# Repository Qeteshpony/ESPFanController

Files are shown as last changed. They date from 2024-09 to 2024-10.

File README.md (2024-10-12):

# ESPFanController



3D Render
3D Render

[Hardware Documentation](https://qeteshpony.github.io/ESPFanController)

Controller for up to three 5V or 12V PWM-Fans with an ESP32 at it's core 

The included yaml file is my config for ESP-Home but of course this can also be programmed in any compatible language you like...

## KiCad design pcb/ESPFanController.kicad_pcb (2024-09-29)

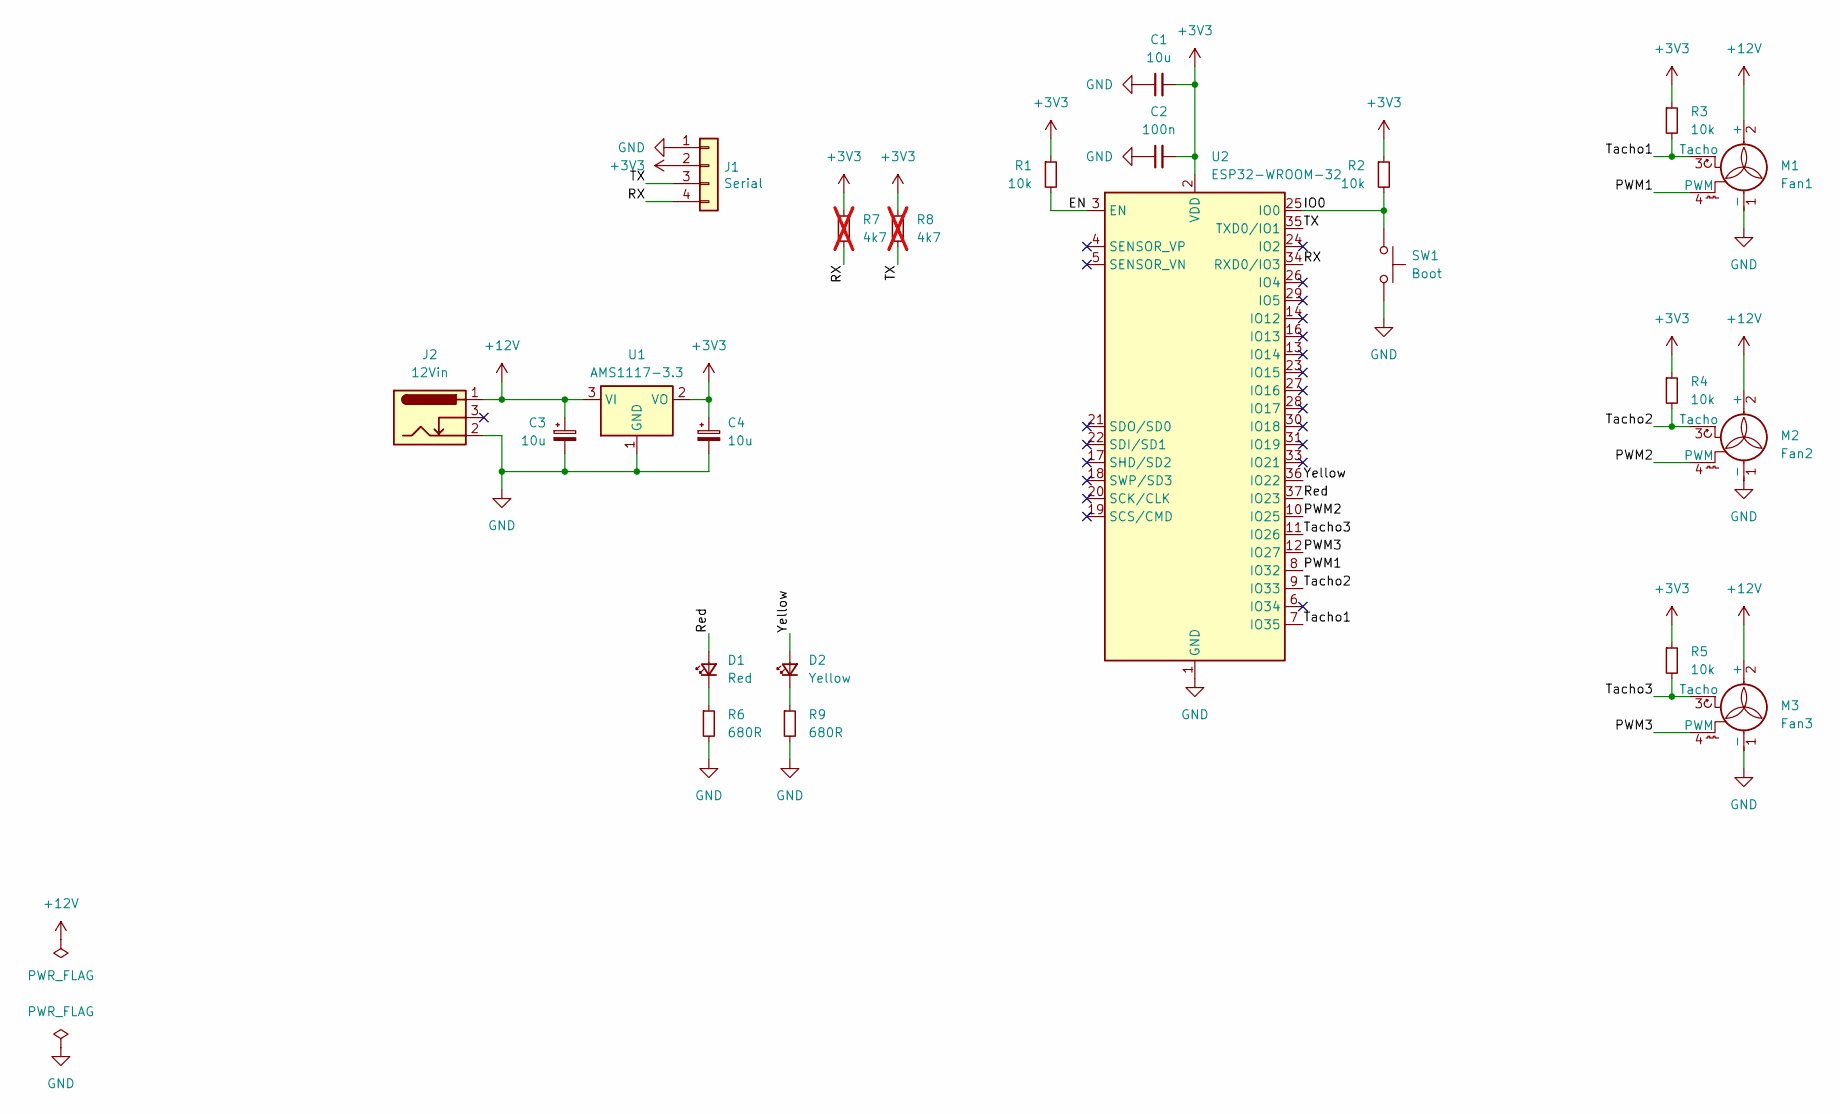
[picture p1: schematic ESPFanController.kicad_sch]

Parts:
C1: 10u; C_0402_1005Metric; LCSC C15525
C2: 100n; C_0402_1005Metric; LCSC C1525
C3, C4: 10u; CP_EIA-3216-18_Kemet-A; LCSC C7171
D1: Red; LED_0603_1608Metric; LCSC C2286
D2: Yellow; LED_0603_1608Metric; LCSC C72038
J1: Serial; JST_PH_B4B-PH-K_1x04_P2.00mm_Vertical; LCSC C131334
J2: 12Vin; BarrelJack_Horizontal
M1: Fan1; FanPinHeader_1x04_P2.54mm_Vertical
M2: Fan2; FanPinHeader_1x04_P2.54mm_Vertical
M3: Fan3; FanPinHeader_1x04_P2.54mm_Vertical
R1, R2, R3, R4, R5: 10k; R_0402_1005Metric; LCSC C25744
R6, R9: 680R; R_0402_1005Metric; LCSC C25130
R7, R8: 4k7; R_0402_1005Metric_Pad0.72x0.64mm_HandSolder; LCSC C25900; not fitted
SW1: Boot; SW_Push_1P1T_XKB_TS-1187A; LCSC C318884
U1: AMS1117-3.3; SOT-223-3_TabPin2; LCSC C6186
U2: ESP32-WROOM-32; LCSC C701341

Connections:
+3V3: C1.2, C2.2, C4.1, J1.2, R1.1, R2.1, R3.1, R4.1, R5.1, R7.1, R8.1, U1.2 (VO), U2.2 (VDD)
+12V: C3.1, J2.1, M1.2 (+), M2.2 (+), M3.2 (+), U1.3 (VI)
/EN: R1.2, U2.3 (EN)
/IO0: R2.2, SW1.2, U2.25 (IO0)
/PWM1: M1.4 (PWM), U2.8 (IO32)
/PWM2: M2.4 (PWM), U2.10 (IO25)
/PWM3: M3.4 (PWM), U2.12 (IO27)
/RX: J1.4, R7.2, U2.34 (RXD0/IO3)
/Red: D1.2 (A), U2.37 (IO23)
/TX: J1.3, R8.2, U2.35 (TXD0/IO1)
/Tacho1: M1.3 (Tacho), R3.2, U2.7 (IO35)
/Tacho2: M2.3 (Tacho), R4.2, U2.9 (IO33)
/Tacho3: M3.3 (Tacho), R5.2, U2.11 (IO26)
/Yellow: D2.2 (A), U2.36 (IO22)
GND: C1.1, C2.1, C3.2, C4.2, J1.1, J2.2, M1.1 (-), M2.1 (-), M3.1 (-), R6.2, R9.2, SW1.1, U1.1 (GND), U2.1 (GND), U2.15 (GND), U2.38 (GND), U2.39 (GND)
unnamed: D1.1 (K), R6.1
unnamed: D2.1 (K), R9.1

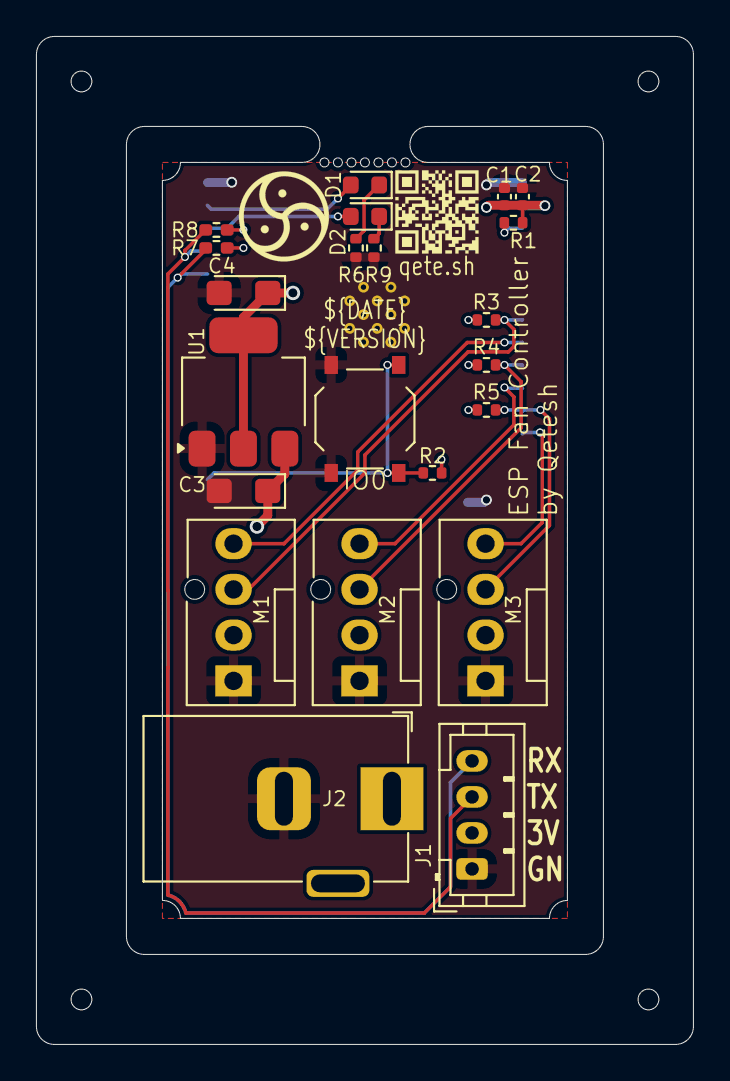
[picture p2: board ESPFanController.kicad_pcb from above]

Board: 2 copper layers, 36.5 x 56.0 mm, 24 parts (1 on the bottom side), 17 nets.

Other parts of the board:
mouse-bite-2mm-slot: VAL**; mouse-bite-2x5mm-slot-onesided-v2

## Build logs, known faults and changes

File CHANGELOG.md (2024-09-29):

# Changelog

## 1.0.0 (2024-09-29)

### Features

* add cutouts to the corners ([45c9f47](https://github.com/Qeteshpony/ESPFanController/commit/45c9f47bbf96ff385ba6cf339b43f648561b01b6))
* add edge rails ([9ef3f67](https://github.com/Qeteshpony/ESPFanController/commit/9ef3f672bd054dec1b5b6f6aff7abb9264d24592))
* add ESP-Home code ([ab3a06b](https://github.com/Qeteshpony/ESPFanController/commit/ab3a06ba9cf272f8cf9e6c14ea871577e3bfbc93))
* add optional pull-ups to serial pins ([45c9f47](https://github.com/Qeteshpony/ESPFanController/commit/45c9f47bbf96ff385ba6cf339b43f648561b01b6))
* add position for pullups ([2205ba8](https://github.com/Qeteshpony/ESPFanController/commit/2205ba8f4f34c5d1d86a76fcbdb6944a744fd259))
* add second LED ([45c9f47](https://github.com/Qeteshpony/ESPFanController/commit/45c9f47bbf96ff385ba6cf339b43f648561b01b6))
* initial commit ([5a03571](https://github.com/Qeteshpony/ESPFanController/commit/5a035719712d4dfddc45b2007910f68341401bdb))

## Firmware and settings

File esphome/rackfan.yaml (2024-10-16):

esphome:
  name: rackfan
  friendly_name: RackFan
  project: 
    name: "Qetesh.RackFanController"
    version: "1.0.0"

esp32:
  board: esp32dev
  framework:
    type: arduino

# Enable logging
logger:

# Enable Home Assistant API
api:
  encryption:
    key: "encryptionkey"

ota:
  - platform: esphome
    password: "otasecret"

wifi:
  ssid: !secret wifi_ssid
  password: !secret wifi_password

web_server:
  
status_led:
  pin: 23


# initialize PWM outputs
output:
  - platform: ledc
    id: pwm1
    pin: 32
    frequency: 25000
    min_power: 0.2
    zero_means_zero: True
    channel: 0
  - platform: ledc
    id: pwm2
    pin: 25
    frequency: 25000
    min_power: 0.2
    zero_means_zero: True
    channel: 2
  - platform: ledc
    id: pwm3
    pin: 27
    frequency: 25000
    min_power: 0.2
    zero_means_zero: True
    channel: 4
  - platform: ledc
    id: pwmled
    pin: 22
    frequency: 1220
    channel: 6
    

# Map fan entities to outputs
fan:  
  - platform: speed
    id: fan1
    output: pwm1
    name: "Fan 1"
    restore_mode: RESTORE_DEFAULT_ON
  - platform: speed
    id: fan2
    output: pwm2
    name: "Fan 2"
    restore_mode: RESTORE_DEFAULT_ON
  - platform: speed
    id: fan3
    output: pwm3
    name: "Fan 3"
    restore_mode: RESTORE_DEFAULT_ON

light:
  # just a power light for now... feel free to use it for whatever
  - platform: monochromatic
    output: pwmled
    id: yellow
    internal: True
    restore_mode: ALWAYS_ON
    

# Add tacho sensors    
sensor:
  - platform: pulse_counter
    pin: 35
    id: tacho1
    name: "Tacho 1"
    update_interval: 5s
    unit_of_measurement: "RPM"
    state_class: measurement
    accuracy_decimals: 0
    icon: "mdi:speedometer"
    filters: 
      - multiply: 0.5 # tacho signal triggers twice per rotation
      - or:
        - throttle: 120s # send at least one value every 120 seconds
        - delta: 20.0 # send immediately if speed changes more than this
  - platform: pulse_counter
    pin: 33
    id: tacho2
    name: "Tacho 2"
    update_interval: 5s
    unit_of_measurement: "RPM"
    state_class: measurement
    accuracy_decimals: 0
    icon: "mdi:speedometer"
    filters: 
      - multiply: 0.5 # tacho signal triggers twice per rotation
      - or:
        - throttle: 120s # send at least one value every 120 seconds
        - delta: 20.0 # send immediately if speed changes more than this
  - platform: pulse_counter
    pin: 26
    id: tacho3
    name: "Tacho 3"
    update_interval: 5s
    unit_of_measurement: "RPM"
    state_class: measurement
    accuracy_decimals: 0
    icon: "mdi:speedometer"
    filters: 
      - multiply: 0.5 # tacho signal triggers twice per rotation
      - or:
        - throttle: 120s # send at least one value every 120 seconds
        - delta: 20.0 # send immediately if speed changes more than this
  - platform: wifi_signal
    name: WiFi Signal Strength
    update_interval: 60s

# add some information about WiFi connection    
text_sensor:
  - platform: wifi_info
    ip_address:
      name: IP
      icon: mdi:ip-network
    ssid:
      name: SSID
      icon: mdi:access-point-network
    mac_address:
      name: MAC
      icon: mdi:hexadecimal
    bssid:
      name: BSSID
      icon: mdi:access-point-network

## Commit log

2024-09-20 feat: initial commit
    [ESPFanController.kicad_pcb, ESPFanController.kicad_sch]
2024-09-20 feat: add position for pullups
    [ESPFanController.kicad_pcb, ESPFanController.kicad_sch]
2024-09-20 feat: add edge rails
    [ESPFanController.kicad_pcb, ESPFanController.kicad_sch]
2024-09-29 feat: add second LED
    feat: add cutouts to the corners
    feat: add optional pull-ups to serial pins
    for I2C use after programming
    [ESPFanController.kicad_pcb, ESPFanController.kicad_sch]
